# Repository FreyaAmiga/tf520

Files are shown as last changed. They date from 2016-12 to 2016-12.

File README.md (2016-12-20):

Terrible Fire 68020 "Accelerator"
=================================

** WARNING THIS IS BETA AT THE MOMENT

This repository contains all the files needed to produce a copy of my accelerator board.

The CPLD Required is a XC9532XL-VQ44

Everything in this repository is released under the GNU GPLv2. You may create or base commercial PCBs from the work in this repository but you must make the sources for all derivative work available. 

Firmware / Requirements
------------

  * Xilinx ISE, 14.7 (the final version - other versions may work but this is the one I support)
  * JTAG Adaptor

PCB Manufacture
---------------

You may get any PCB manufacturer to produce the board for you. The board is 2-layer. I recommend DirtyPCBs 

This link takes you to a store to buy them 

http://dirtypcbs.com/store/designer/details/12476/1120/sl520-rev3-zip

To populate a PCB you will likely need the following tools.

  * Soldering Station (with hot air rework and an iron - probably with a few tips)
  * Stereo Microscope (or similar for soldering under)
  * Bench Power Supply (to verify the regulator circuit)
 
There will be those with more experience and great eyesight that could manage it with just a soldering iron but I am trying to be realistic here.

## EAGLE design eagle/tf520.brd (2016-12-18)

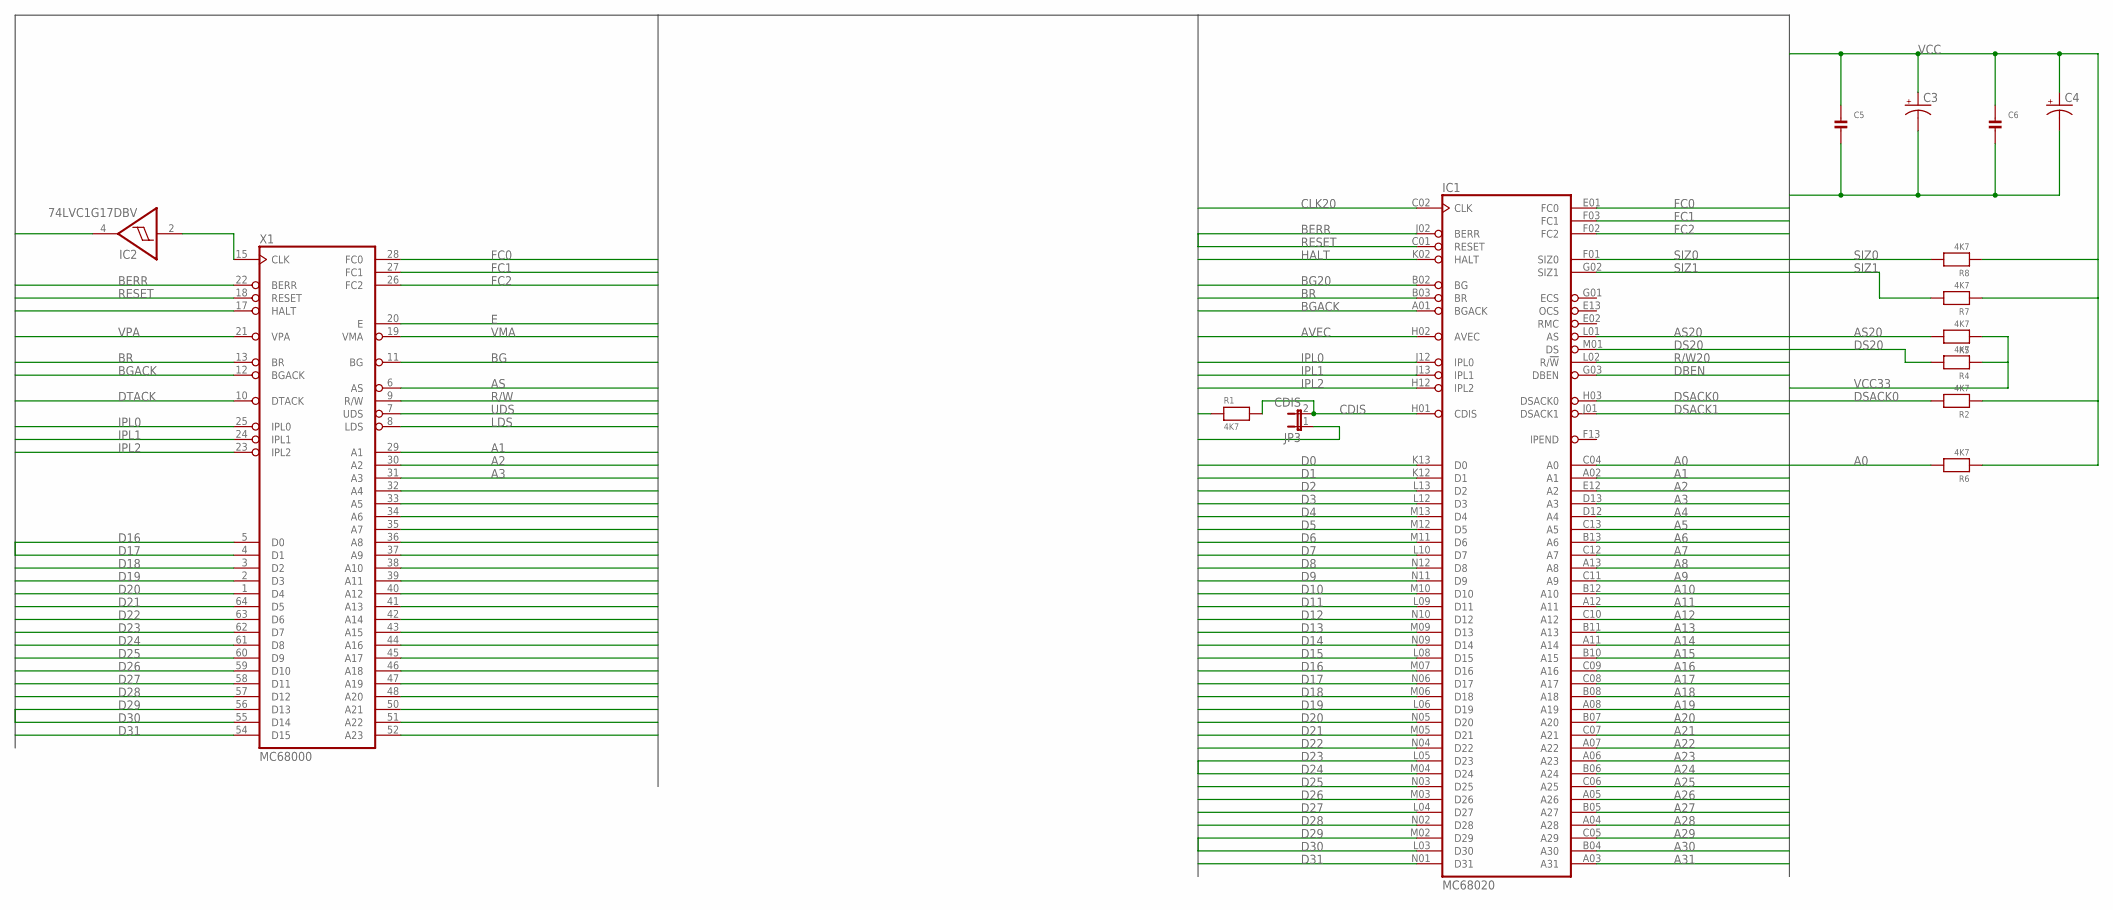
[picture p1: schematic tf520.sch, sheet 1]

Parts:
C3, C4: CAP_POLD; PANASONIC_D
C5, C6: CAP_CERAMIC1206; 1206
IC1: MC68020; MPGA114
IC2: 74LVC1G17DBV; SOT23-5
JP3: CDIS; 1X02
R1, R2, R4, R5, R6, R7, R8: 4K7; 1206
X1: MC68000; DIL64

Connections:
A0: IC1.C04 (A0), R6.2; also elsewhere on the board
A1: IC1.A02 (A1), X1.29 (A1)
A2: IC1.E12 (A2), X1.30 (A2)
A3: IC1.D13 (A3), X1.31 (A3)
A4: IC1.D12 (A4), X1.32 (A4)
A5: IC1.C13 (A5), X1.33 (A5)
A6: IC1.B13 (A6), X1.34 (A6)
A7: IC1.C12 (A7), X1.35 (A7)
A8: IC1.A13 (A8), X1.36 (A8)
A9: IC1.C11 (A9), X1.37 (A9)
A10: IC1.B12 (A10), X1.38 (A10)
A11: IC1.A12 (A11), X1.39 (A11)
A12: IC1.C10 (A12), X1.40 (A12)
A13: IC1.B11 (A13), X1.41 (A13)
A14: IC1.A11 (A14), X1.42 (A14)
A15: IC1.B10 (A15), X1.43 (A15)
A16: IC1.C09 (A16), X1.44 (A16); also elsewhere on the board
A17: IC1.C08 (A17), X1.45 (A17); also elsewhere on the board
A18: IC1.B08 (A18), X1.46 (A18); also elsewhere on the board
A19: IC1.A08 (A19), X1.47 (A19); also elsewhere on the board
A20: IC1.B07 (A20), X1.48 (A20)
A21: IC1.C07 (A21), X1.50 (A21)
A22: IC1.A07 (A22), X1.51 (A22)
A23: IC1.A06 (A23), X1.52 (A23)
A24: IC1.B06 (A24)
A25: IC1.C06 (A25)
A26: IC1.A05 (A26)
A27: IC1.B05 (A27)
A28: IC1.A04 (A28)
A29: IC1.C05 (A29)
A30: IC1.B04 (A30)
A31: IC1.A03 (A31)
AS: X1.6 (AS); also elsewhere on the board
AS20: IC1.L01 (AS), R5.2; also elsewhere on the board
AVEC: IC1.H02 (AVEC); also elsewhere on the board
BERR: IC1.J02 (BERR), X1.22 (BERR); also elsewhere on the board
BG: X1.11 (BG); also elsewhere on the board
BG20: IC1.B02 (BG); also elsewhere on the board
BGACK: IC1.A01 (BGACK), X1.12 (BGACK); also elsewhere on the board
BR: IC1.B03 (BR), X1.13 (BR)
CDIS: IC1.H01 (CDIS), JP3.2, R1.2
CLK7M: IC2.4 (O); also elsewhere on the board
CLK7M_RAW: IC2.2 (I), X1.15 (CLK)
CLK20: IC1.C02 (CLK); also elsewhere on the board
D0: IC1.K13 (D0)
D1: IC1.K12 (D1)
D2: IC1.L13 (D2)
D3: IC1.L12 (D3)
D4: IC1.M13 (D4)
D5: IC1.M12 (D5)
D6: IC1.M11 (D6)
D7: IC1.L10 (D7)
D8: IC1.N12 (D8)
D9: IC1.N11 (D9)
D10: IC1.M10 (D10)
D11: IC1.L09 (D11)
D12: IC1.N10 (D12)
D13: IC1.M09 (D13)
D14: IC1.N09 (D14)
D15: IC1.L08 (D15)
D16: IC1.M07 (D16), X1.5 (D0)
D17: IC1.N06 (D17), X1.4 (D1)
D18: IC1.M06 (D18), X1.3 (D2)
D19: IC1.L06 (D19), X1.2 (D3)
D20: IC1.N05 (D20), X1.1 (D4)
D21: IC1.M05 (D21), X1.64 (D5)
D22: IC1.N04 (D22), X1.63 (D6)
D23: IC1.L05 (D23), X1.62 (D7)
D24: IC1.M04 (D24), X1.61 (D8)
D25: IC1.N03 (D25), X1.60 (D9)
D26: IC1.M03 (D26), X1.59 (D10)
D27: IC1.L04 (D27), X1.58 (D11)
D28: IC1.N02 (D28), X1.57 (D12)
D29: IC1.M02 (D29), X1.56 (D13)
D30: IC1.L03 (D30), X1.55 (D14)
D31: IC1.N01 (D31), X1.54 (D15)
DBEN: IC1.G03 (DBEN)
DS20: IC1.M01 (DS), R4.2; also elsewhere on the board
DSACK0: IC1.H03 (DSACK0), R2.2
DSACK1: IC1.J01 (DSACK1); also elsewhere on the board
DTACK: X1.10 (DTACK); also elsewhere on the board
E: X1.20 (E); also elsewhere on the board
FC0: IC1.E01 (FC0), X1.28 (FC0); also elsewhere on the board
FC1: IC1.F03 (FC1), X1.27 (FC1); also elsewhere on the board
FC2: IC1.F02 (FC2), X1.26 (FC2); also elsewhere on the board
GND: C3.-, C4.-, C5.2, C6.2, IC1.A10 (GND), IC1.B01 (GND), IC1.B09 (GND), IC1.C03 (GND), IC1.F12 (GND), IC1.G12 (GND), IC1.H13 (GND), IC1.J03 (GND), IC1.K01 (GND), IC1.K03 (GND), IC1.L07 (GND), IC1.L11 (GND), IC1.N07 (GND), IC2.3 (GND), JP3.1, X1.16 (GND), X1.53 (GND); also elsewhere on the board
HALT: IC1.K02 (HALT), X1.17 (HALT); also elsewhere on the board
IPL0: IC1.J12 (IPL0), X1.25 (IPL0)
IPL1: IC1.J13 (IPL1), X1.24 (IPL1)
IPL2: IC1.H12 (IPL2), X1.23 (IPL2)
LDS: X1.8 (LDS); also elsewhere on the board
R/W: X1.9 (R/W); also elsewhere on the board
R/W20: IC1.L02 (R/!W); also elsewhere on the board
RESET: IC1.C01 (RESET), X1.18 (RESET); also elsewhere on the board
SIZ0: IC1.F01 (SIZ0), R8.2; also elsewhere on the board
SIZ1: IC1.G02 (SIZ1), R7.2; also elsewhere on the board
UDS: X1.7 (UDS); also elsewhere on the board
VCC: C3.+, C4.+, C5.1, C6.1, IC1.A09 (VCC), IC1.D01 (VCC), IC1.D02 (VCC), IC1.D03 (VCC), IC1.E03 (VCC), IC1.G11 (VCC), IC1.G13 (VCC), IC1.M08 (VCC), IC1.N08 (VCC), IC1.N13 (VCC), IC2.5 (VCC), R1.1, R2.1, R6.1, R7.1, R8.1, X1.14 (VCC), X1.49 (VCC); also elsewhere on the board
VCC33: R4.1, R5.1; also elsewhere on the board
VMA: X1.19 (VMA); also elsewhere on the board
VPA: X1.21 (VPA); also elsewhere on the board

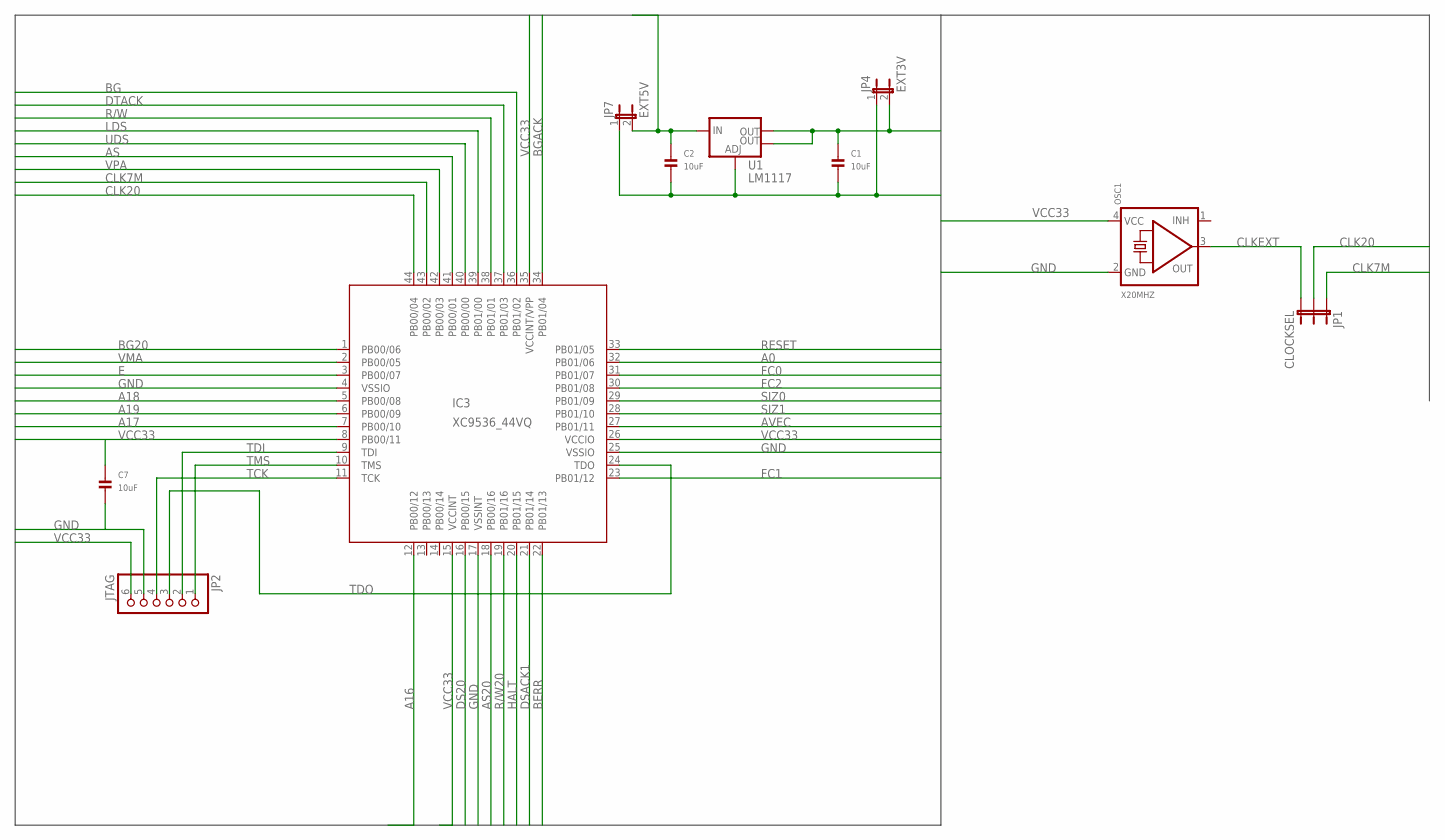
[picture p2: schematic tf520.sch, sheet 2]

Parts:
C1, C2, C7: 10uF; 1206
IC3: XC9536_44VQ; SQFP-S-10X10-44
JP1: CLOCKSEL; 1X03
JP2: JTAG; 1X06_ROUND
JP4: EXT3V; 1X02
JP7: EXT5V; JP1
OSC1: X20MHZ; OSC_7X5MM
U1: LM1117; SOT223

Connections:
A0: IC3.32 (PB01/06); also elsewhere on the board
A16: IC3.12 (PB00/12); also elsewhere on the board
A17: IC3.7 (PB00/10); also elsewhere on the board
A18: IC3.5 (PB00/08); also elsewhere on the board
A19: IC3.6 (PB00/09); also elsewhere on the board
AS: IC3.41 (PB00/01); also elsewhere on the board
AS20: IC3.18 (PB00/16); also elsewhere on the board
AVEC: IC3.27 (PB01/11); also elsewhere on the board
BERR: IC3.22 (PB01/13); also elsewhere on the board
BG: IC3.36 (PB01/02); also elsewhere on the board
BG20: IC3.1 (PB00/06); also elsewhere on the board
BGACK: IC3.34 (PB01/04); also elsewhere on the board
CLK7M: IC3.43 (PB00/02), JP1.1; also elsewhere on the board
CLK20: IC3.44 (PB00/04), JP1.2; also elsewhere on the board
CLKEXT: JP1.3, OSC1.3 (OUT)
DS20: IC3.16 (PB00/15); also elsewhere on the board
DSACK1: IC3.21 (PB01/14); also elsewhere on the board
DTACK: IC3.37 (PB01/03); also elsewhere on the board
E: IC3.3 (PB00/07); also elsewhere on the board
FC0: IC3.31 (PB01/07); also elsewhere on the board
FC1: IC3.23 (PB01/12); also elsewhere on the board
FC2: IC3.30 (PB01/08); also elsewhere on the board
GND: C1.2, C2.2, C7.2, IC3.4 (VSSIO), IC3.17 (VSSINT), IC3.25 (VSSIO), JP2.5, JP4.1, JP7.1, OSC1.2 (GND), U1.1 (ADJ); also elsewhere on the board
HALT: IC3.20 (PB01/15); also elsewhere on the board
LDS: IC3.39 (PB01/00); also elsewhere on the board
R/W: IC3.38 (PB01/01); also elsewhere on the board
R/W20: IC3.19 (PB01/16); also elsewhere on the board
RESET: IC3.33 (PB01/05); also elsewhere on the board
SIZ0: IC3.29 (PB01/09); also elsewhere on the board
SIZ1: IC3.28 (PB01/10); also elsewhere on the board
TCK: IC3.11 (TCK), JP2.4
TDI: IC3.9 (TDI), JP2.2
TDO: IC3.24 (TDO), JP2.3
TMS: IC3.10 (TMS), JP2.1
UDS: IC3.40 (PB00/00); also elsewhere on the board
VCC: C2.1, JP7.2, U1.3 (IN); also elsewhere on the board
VCC33: C1.1, C7.1, IC3.8 (PB00/11), IC3.15 (VCCINT), IC3.26 (VCCIO), IC3.35 (VCCINT/VPP), JP2.6, JP4.2, OSC1.4 (VCC), U1.2 (OUT), U1.4 (OUT); also elsewhere on the board
VMA: IC3.2 (PB00/05); also elsewhere on the board
VPA: IC3.42 (PB00/03); also elsewhere on the board

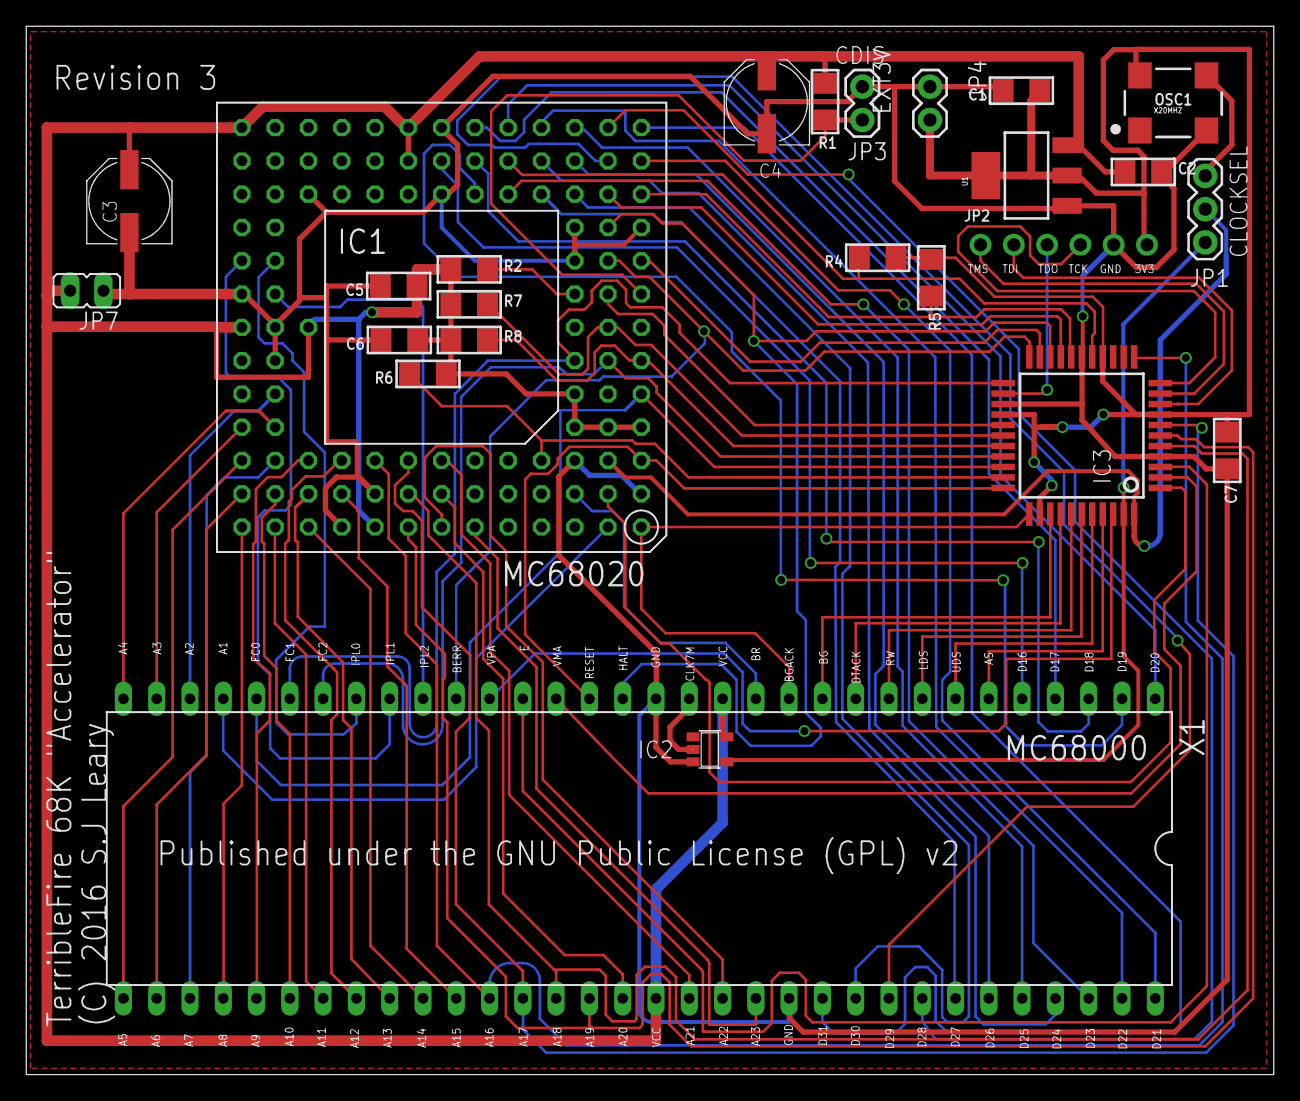
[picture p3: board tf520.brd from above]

Board: 2 copper layers, 95.2 x 80.0 mm, 25 parts (0 on the bottom side), 81 nets.

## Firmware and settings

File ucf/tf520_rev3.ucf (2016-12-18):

# 
# This file is part of the Terrible Fire Amiga Accelerator.
# 
# Copyright (c) 2016, Stephen J. Leary <stephen@terriblefire.com>
# 
# All rights reserved.
#
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

#Clocks
NET "CLKCPU"    LOC = "P44" ;
NET "CLKCPU" BUFG=CLK;
NET "CLKCPU" TNM_NET = "CLKCPU"; # gives the net clk a group name as CLKCPU
TIMESPEC "TS_CLKCPU" = PERIOD "CLKCPU" 20 ns ; # add 20 ns PERIOD constraint the
OFFSET = IN 5 ns BEFORE "CLKCPU" ; # add  offset in constraint
OFFSET = OUT 5 ns AFTER "CLKCPU" ; # add  offset out constraint

NET "CLK7M"    LOC = "P43" ;
NET "CLK7M" BUFG=CLK;
NET "CLK7M" TNM_NET = "CLK7M"; # gives the net clk a group name as CLK7M
TIMESPEC "TS_CLK7M" = PERIOD "CLK7M" 139 ns ; # add 139 ns PERIOD constraint the
OFFSET = IN 15 ns BEFORE "CLK7M" ; # add  offset in constraint
OFFSET = OUT 15 ns AFTER "CLK7M" ; # add  offset out constraint

# 68K Signals
NET "VPA"    LOC = "P42";
NET "AS"     LOC = "P41";
NET "UDS"    LOC = "P40";
NET "LDS"    LOC = "P39";
NET "RW00"   LOC = "P38";
NET "DTACK"  LOC = "P37";
NET "BG"     LOC = "P36";
NET "BGACK"  LOC = "P34";
NET "VMA"    LOC = "P02" ;
NET "E"      LOC = "P03" ;
NET "BERR"   LOC = "P22";

NET "A0"    LOC = "P32";
NET "A<16>"	  LOC = "P12";
NET "A<17>"	  LOC = "P07";
NET "A<18>"	  LOC = "P05";
NET "A<19>"	  LOC = "P06";

# 68020 Signals

#NET "HALT"	  LOC = "P20";
#NET "RESET"  LOC = "P33" ;
#NET "HIGH"	  LOC = "P08" ; // do not drive low.

#NET "NC<0>"	  LOC = "P13" ;
#NET "NC<1>"	  LOC = "P14" ;


NET "BG20"	  LOC = "P01" ;
NET "DSACK1"  LOC = "P21" ;
NET "RW20"    LOC = "P19";
NET "AS20"	  LOC = "P18" ;
NET "DS20"	  LOC = "P16" ;

NET "AVEC"	  LOC = "P27" ;
NET "SIZ<1>"  LOC = "P28" ;
NET "SIZ<0>"  LOC = "P29" ;

NET "FC<0>"   LOC = "P31"  ;
NET "FC<1>"	  LOC = "P23" ;
NET "FC<2>"	  LOC = "P30" ;

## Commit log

2016-10-24 Committing the rev2 eagle files and the gerbers of rev1 and rev2
    [tf520.brd, tf520.sch]
2016-12-18 Adding the Atari ST fixes Reorganizing the repos. Added jed files for rev 2 and rev 3 Published the REV 3 sources and ucf
    [tf520.brd, tf520.sch]
2016-12-18 updated the pcb link

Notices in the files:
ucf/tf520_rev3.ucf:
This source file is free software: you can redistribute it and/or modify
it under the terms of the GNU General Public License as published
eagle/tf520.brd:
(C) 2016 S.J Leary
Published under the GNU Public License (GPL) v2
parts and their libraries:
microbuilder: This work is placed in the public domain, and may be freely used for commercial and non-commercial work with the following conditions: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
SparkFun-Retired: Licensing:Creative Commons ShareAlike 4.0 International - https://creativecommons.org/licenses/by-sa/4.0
